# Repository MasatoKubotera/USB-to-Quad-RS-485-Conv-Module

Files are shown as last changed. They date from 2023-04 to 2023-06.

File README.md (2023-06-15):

<html lang="en">

<head>
    <meta charset="uft-8">
    <meta name="author" content="Masato Kubotera">
    <meta name="description" content="">
</head>

<body>
    <p><strong>This product is currently under development!</strong></p>
    <h1>USB to Quad RS-485 Conv. Module</h1>
        <p>
            This product is USB to 4 RS-485 conversion module. The FTDI FT4232H is used for USB to quad UART conversion, and the Analog Devices ADM3078E is used for UART to RS-485 conversion. USB is 2.0 High Speed (480 Mb/s) and RS-485 supports a maximum baud rate of 16 MBps. The RS-485 I/O voltage is 3.3 V and is supplied by USB bus power from the regulator on the board. This product has a internal EEPROM and programmable in-circuit over USB using a utility program called FT_PROG available from FTDI’s web site (www.ftdichip.com). <br><br>
            Note: For this product, RI must be RS485 enabled (Enables the RI pin to be used as the TXDEN signal for RS485 busses) using FT_PROG in order to convert USB to RS-485 for transmission.
        </p>
    <h2>Features Rev. 1</h2>
        <p>
            <table>
                <tr>
                    <th>Top Surface of PCB</th>
                    <th>Bottom Surface of PCB</th>
                    <th>Assembled Electronic Components</th>
                </tr>
                <tr>
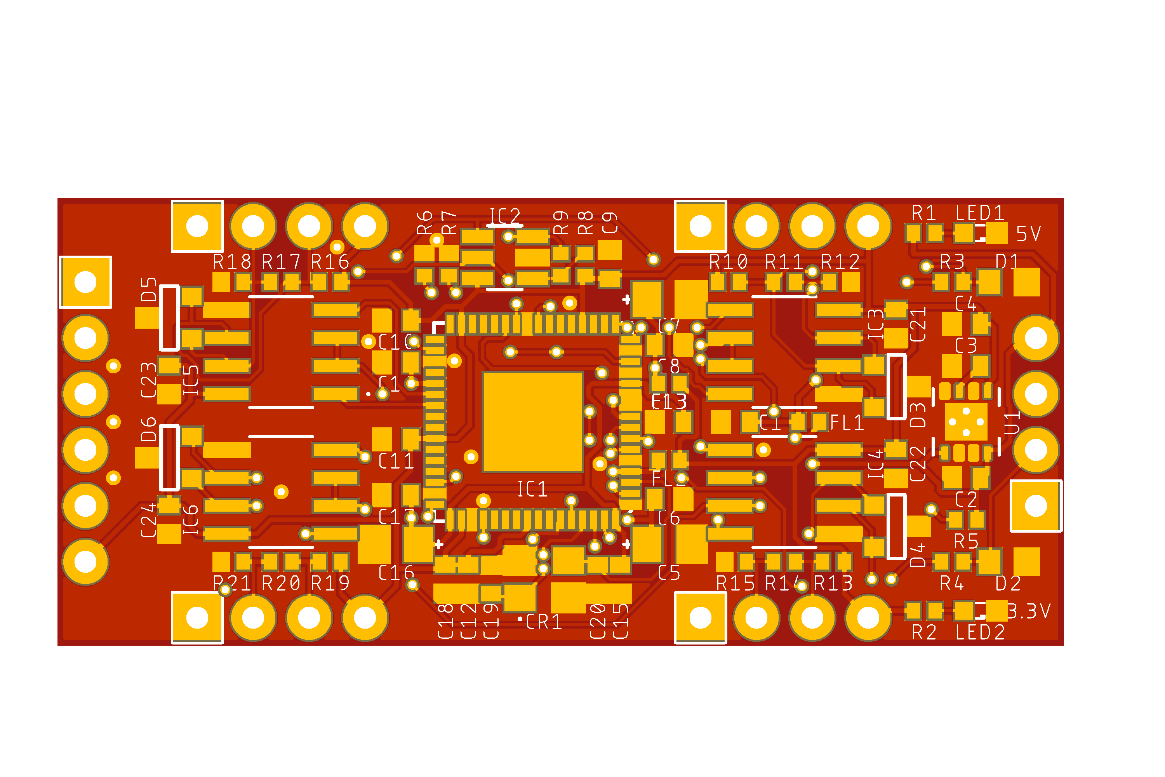
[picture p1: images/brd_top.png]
                    <td></td>
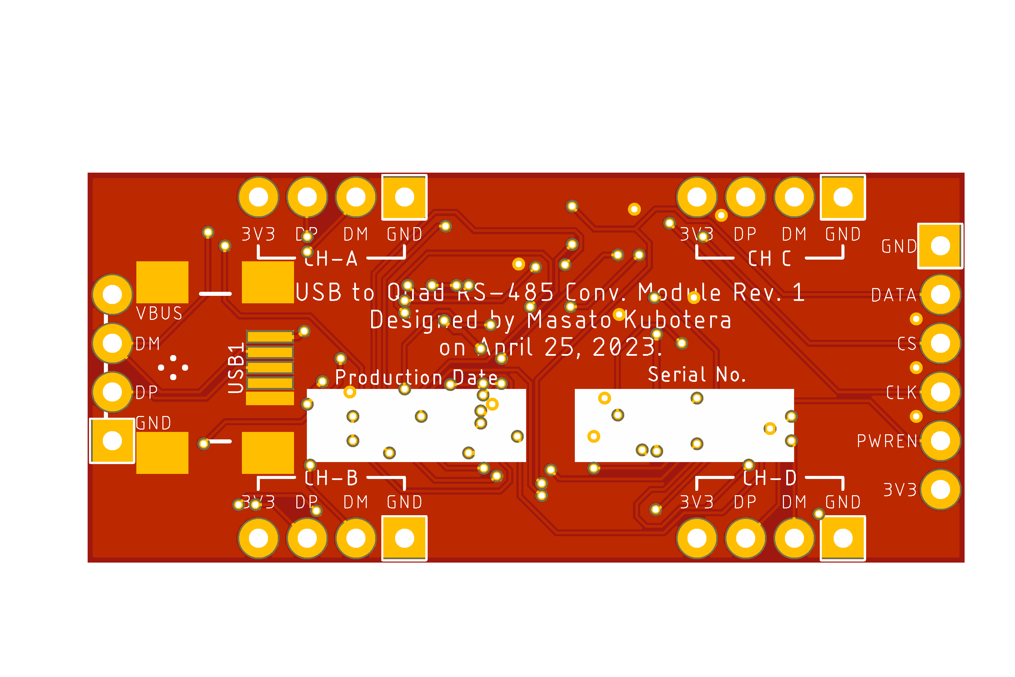
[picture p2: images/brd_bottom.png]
                    <td></td>
                    <td></td>
                </tr>
            </table>
        </p>
    <h3>PCB</h3>
        <p>
            <ul>
                <li>58 mm x 22.5 mm PCB layout</li>
                <li>
                    Two types of USB connectors
                    <ul>
                        <li>USB Mini-B Connector</li>
                        <li>1" (2.54mm) pitch through-holes for pin headers
                            <ul>
                                <li>VBUS</li>
                                <li>DM: USB Data Signal Minus</li>
                                <li>DP: USB Data Signal Plus</li>
                                <li>GND: Common Ground</li>
                            </ul>
                        </li>
                    </ul>
                </li>
                <li>
                    4 x RS-485 ports
                    <ul>
                        <li>1" (2.54mm) pitch through-holes for pin headers
                            <ul>
                                <li>3V3: 3.3 V power output (Power generated by the regulator on the board from USB bus power)</li>
                                <li>DP: RS-485 Data Signal Plus</li>
                                <li>DM: RS-485 Data Signal Minus</li>
                                <li>GND: Common Ground</li>
                            </ul>
                        </li>
                    </ul>
                </li>
                <li>
                    1 x Expansion port for FTDI FH4232HQ
                    <ul>
                        <li>1" (2.54mm) pitch through-holes for pin headers
                            <ul>
                                <li>3V3: 3.3 V power output (Power generated by the regulator on the board from USB bus power)</li>
                                <li>PWREN: Connected to FT4232HQ Pin#: 60 PWREN#</li>
                                <li>CLK: Connected to FT4232HQ Pin#: 62 EECLK</li>
                                <li>CS: Connected to FT4232HQ Pin#: 63 EECS</li>
                                <li>DATA: Connected to FT4232HQ Pin#: 61 EEDATA</li>
                                <li>GND: Common Ground</li>
                            </ul>
                    This port can be used for 4-channel transmit/receive LED display by decoding EEDATA data using 74HCT595, etc. Check the <a href="https://ftdichip.com/wp-content/uploads/2020/08/DS_FT4232H.pdf#page=33">Data Sheet</a> for details.
                        </li>
                    </ul>
                </li>
            </ul>
        </p>
    <h2>Development Environments</h2>
    <p>
        This product is designed with the following software.
            <ul>
                <li><a href="https://www.autodesk.com/products/eagle/overview">Autodesk Eagle 9.6.2</a></li>
            </ul>
    </p>
    <h2>Repository Contents</h2>
        <p>
            <dl>
                <dt><a href="/images">\images</a></dt>
                <dd>PCB preview images and capture of design screen</dd>
                <dt><a href="/libraries">\libraries</a></dt>
                <dd>Libraries used in Autodesk Eagle design</dd>
                <!--
                    <dt><a href="/documents">\documents</a> </dt>
                    <dd>Documentation for making and using this product</dd>
                -->
                <dt><a href="/pcb_order">\pcb_order</a> </dt>
                <dd>Gerber data and documentation for ordering PCB</dd>
                <dt><a href="/schematic.pdf">schematic.pdf</a></dt>
                <dd>Circuit diagram of this product</dd>
                <dt>*.brd</dt>
                <dd>Board wiring design file by Autodesk Eagle</dd>
                <dt>*.sch</dt>
                <dd>Circuit diagram design file by Autodesk Eagle</dd>
                <dt><a href="/.gitignore">.gitignore</a></dt>
                <dd>A file that tells Git not to track a particular file</dd>
                <dt><a href="/LICENSE">LICENSE</a></dt>
                <dd>License to use this product</dd>
            </dl>
        </p>
    <h2>Documentation</h2>
        <p>
            The following documents are available for this product.
            <ul>
                <li><a href="/pcb_order/README.md">\pcb_order\README.md</a>: Information for ordering the PCB</li>
            </ul>
        </p>
    <h2>References</h2>
        <p>
            This product was designed with reference to the following products.
            <ul>
                <li><a href="https://ftdichip.com/products/ft4232h-mini-module/">FTDI USB Hi-Speed FT4232H Evaluation Module: FT4232H Mini Module</a></li>
                <li><a href="https://kondo-robot.com/product/02133">KONDO RS485USB/Serial Conversion Adapter</a></li>
            </ul>
            In addition, the following documents were referenced in the design
            <ul>
                <li><a href="https://www.ftdichip.com/Support/Documents/AppNotes/AN_146_USB_Hardware_Design_Guidelines_for_FTDI_ICs.pdf">FTDI USB Hardware Design Guidelines for FTDI ICs</a></li>
                <li><a href="https://www.analog.com/media/en/analog-dialogue/volume-47/number-2/articles/safeguard-your-rs-485-communication-networks.pdf">Analog Devices Safeguard Your RS-485 Communication Networks from Harmful EMC Events</a></li>
                <li><a href="https://kondo-robot.com/w/wp-content/uploads/2014-B3M_series_manual_Ver.1.1.3.pdf#page=8">KONDO B3M Series Manual Ver1.13 pp.8</a></li>
            </ul>
        </p>
    <h2>Acknowledgements</h2>
        <p>
            The background to the development of this product was the development of QUADDXL, which was introduced in the following paper.
            <ul>
                <li>Bestmann, M., Güldenstein, J., Zhang, J. : High-Frequency Multi Bus Servo and Sensor Communication Using the Dynamixel Protocol. RoboCup 2019: Robot World Cup XXIII, pp.16–29 (2019)</li>
            </ul>
            Development data and other information on QUADDXL are available in the following repositories.
            <ul>
                <li><a href="https://github.com/bit-bots/bitbots_quaddxl">bit-bots/bitbots_quaddxl</a>: USB to RS485 Converter using FT4232H</li>
            </ul>
            I would like to take this opportunity to thank you.
        </p>
    <h2>Contact</h2>
        <p>
            If you have any questions, please contact the designer of this product, Masato Kubodera, by <a href="mailto:masato.kubotera@sustaina-op.com">e-mail</a>.<br>
            E-mail: <a href="mailto:masato.kubotera@sustaina-op.com">masato.kubotera@sustaina-op.com</a>
        </p>
    <h2>License Information</h2>
        <p>
            This product is open source. Please review the <a href="/LICENSE">LICENSE</a> for license information.<br>
            <br>
            This product by Masato Kubotera is licensed under a <a href="http://creativecommons.org/licenses/by-nc-sa/4.0/">Creative Commons Attribution-NonCommercial-ShareAlike 4.0 International License</a>.
        </p>
</body>
</html>

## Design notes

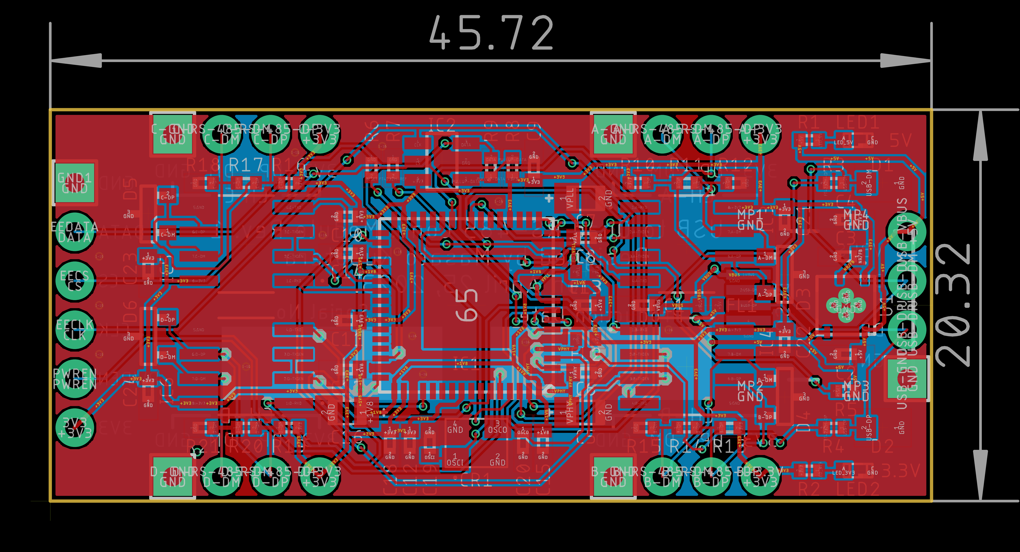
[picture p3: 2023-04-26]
images/brd.png

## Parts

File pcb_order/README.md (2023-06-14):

<html lang="en">

<head>
	<meta charset="uft-8">
	<meta name="author" content="Masato Kubotera">
    <meta name="description" content="">
</head>

<body>
	<h1>PCB / PCBA Order</h1>
        <p>
            PCB/PCBA ordering were outsourced to <a href="https://jlcpcb.com/">JLCPCB</a>.<br>
            The following files were used to generate files for PCB/PCBA orders.
            <ul>
                <li>Eagle Design File:
                    <a href="https://github.com/JLCPCB/jlcpcb-eagle/blob/master/design%20rules/jlcpcb-2layers.dru">jlcpcb-2layers.dru</a>
                </li>
                <li>Eagle CAM File:
                    <a href="https://github.com/JLCPCB/jlcpcb-eagle/blob/master/cam/jlcpcb_2_layer_v9.cam">jlcpcb_2_layer_v9.cam</a>
                </li>
                <li>BOM/CPL Exporter ULPs:
                    <a href="https://github.com/JLCPCB/jlcpcb-eagle/blob/master/ulps/jlcpcb_smta_exporter.ulp">jlcpcb_smta_exporter.ulp</a>
                </li>
            </ul>
            These are distributed in <a href="https://github.com/JLCPCB/jlcpcb-eagle">github.com/JLCPCB/jlcpcb-eagle</a>.<br>
        </p>
    <h2>PCB Order Specifications</h2>
        <p>           
            <table>
                <tr>
                    <th>PCB Top Image</th>
                    <th>PCB Bottom Image</th>
                </tr>
                <tr>
                    <td></td>
                    <td></td>
                </tr>
            </table>
            The following  files used to order the PCB and their specifications. 
            <ul>
                <li>Gerber data: <a href="Gerber_date.zip">Gerber_date.zip</a></li>
            </ul>
            <details close>
                <summary>Click for more specifications</summary>
                <ul>                
                    <li>Base Material: FR-4</li>
                    <li>Layers: 2</li>
                    <li>Dimension: 45.72 mm* 20.32 mm</li>
                    <li>Product Type: Industrial/Consumer electronics</li>
                    <li>Different Design: 1</li>
                    <li>Delivery Format: Single PCB</li>
                    <li>PCB Thickness: 1.6</li>
                    <li>Impedance Control: no</li>
                    <li>PCB Color: Red</li>
                    <li>Silkscreen: White</li>
                    <li>Surface Finish: HASL(with lead)</li>
                    <li>Outer Copper Weight: 1 oz</li>
                    <li>Via Covering: Tented</li>
                    <li>Board Outline Tolerance: ±0.2mm(Regular)</li>
                    <li>Confirm Production file: No</li>                
                    <li>Remove Order Number: Yes</li>
                    <li>Deburring/Edge rounding: No</li>
                    <li>Flying Probe Test: Fully Test</li>
                    <li>Gold Fingers: No</li>
                    <li>Castellated Holes: No</li>
                    <li>4-Wire Kelvin Test: No</li>
                    <li>Paper between PCBs: No</li>
                    <li>Appearance Quality: IPC Class 2 Standard</li>
                    <li>Silkscreen Technology: Ink-jet/Screen Printing</li>
                    <li>Package Box: With JLCPCB logo</li>
                </ul>
            </details>
        </p>
    <h2>PCBA Order Specifications</h2>
        <p>
            <table>
                <tr><th>PCBA Image</th></tr>
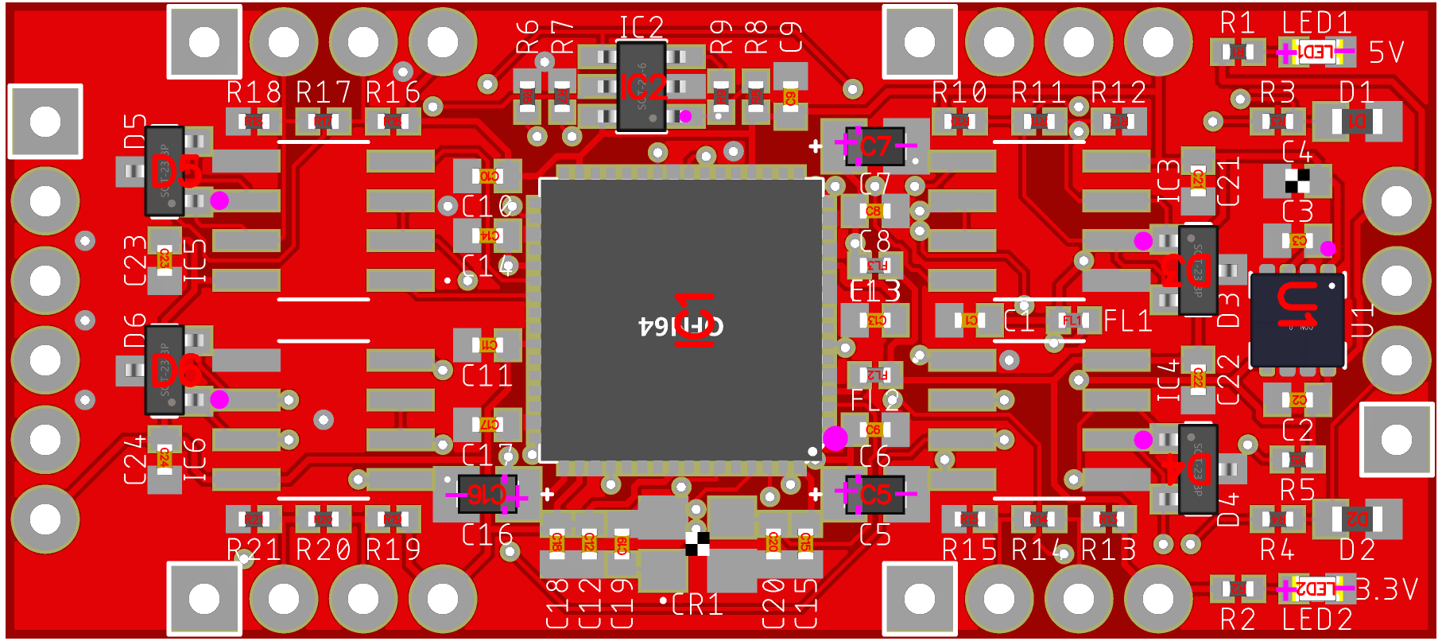
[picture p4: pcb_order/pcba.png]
                <tr><td></td></tr>
            </table>
            The following files used to order the PCBA and their specifications.
            <ul>
                <li>BOM File: <a href="USB-to-Quad-RS-485-Conv-Module_top_bom.csv">USB-to-Quad-RS-485-Conv-Module_top_bom.csv</a></li>
                <li>CPL File: <a href="USB-to-Quad-RS-485-Conv-Module_top_cpl.csv">USB-to-Quad-RS-485-Conv-Module_top_cpl.csv</a></li>
            </ul>
            The following components were installed by PCBA.
            <table>
                <tr>
                    <th>Part Image</th>
                    <th>Top Designator</th>
                    <th>MFR.Part #</th>
                    <th>JLCPCB Part #</th>
                    <th>Manufacturer</th>
                    <th>Part Detail</th>
                </tr>
                <tr>
                    <td></td>
                    <td>C1,C3</td>
                    <td>CC0402JRX7R9BB103</td>
                    <td><a href="https://jlcpcb.com/partdetail/Yageo-CC0402JRX7R9BB103/C272878">C272878</a></td>
                    <td>YAGEO</td>
                    <td>Multilayer Ceramic Capacitor SMD 10nF 50V ±5% X7R 0402</td>
                </tr>
                <tr>
                    <td></td>
                    <td>C2</td>
                    <td>CC0402KRX7R5BB105</td>
                    <td><a href="https://jlcpcb.com/partdetail/Yageo-CC0402KRX7R5BB105/C115046">C115046</a></td>
                    <td>YAGEO</td>
                    <td>Multilayer Ceramic Capacitor SMD 1uF 6.3V ±10% X7R 0402</td>
                </tr>
                <tr>
                    <td></td>
                    <td>C4</td>
                    <td>GRM155Z71A225KE01D</td>
                    <td><a href="https://jlcpcb.com/partdetail/3468099-GRM155Z71A225KE01D/C2997286">C2997286</a></td>
                    <td>Murata Electronics</td>
                    <td>Multilayer Ceramic Capacitor SMD 2.2uF 10V ±10% X7R 0402</td>
                </tr>
                <tr>
                    <td></td>
                    <td>C5,C7,C16</td>
                    <td>TAJR475K006RNJ</td>
                    <td><a href="https://jlcpcb.com/partdetail/KyoceraAvx-TAJR475K006RNJ/C308815">C308815</a></td>
                    <td>Kyocera AVX</td>
                    <td>Tantalum Capacitor SMD 4.7uF 6.3V ±10% 7Ω@100kHz 0805</td>
                </tr>
                <tr>
                    <td></td>
                    <td>C6,C8,C9,C10,C11,C12,C13,C14,C15,C17,C18,C21,C22,C23,C24</td>
                    <td>CC0402JRX7R7BB104</td>
                    <td><a href="https://jlcpcb.com/partdetail/Yageo-CC0402JRX7R7BB104/C541464">C541464</a></td>
                    <td>YAGEO</td>
                    <td>Multilayer Ceramic Capacitor SMD 100nF 16V ±5% X7R 0402</td>
                </tr>
                <tr>
                    <td></td>
                    <td>C19,C20</td>
                    <td>CC0402GRNPO9BN300</td>
                    <td><a href="https://jlcpcb.com/partdetail/Yageo-CC0402GRNPO9BN300/C277479">C277479</a></td>
                    <td>YAGEO</td>
                    <td>Multilayer Ceramic Capacitor SMD 30pF 50V ±2% NP0 0402</td>
                </tr>
                <tr>
                    <td></td>
                    <td>CR1</td>
                    <td>7V12006001</td>
                    <td><a href="https://jlcpcb.com/partdetail/TxcCorp-7V12006001/C5203634">C5203634</a></td>
                    <td>TXC Corp</td>
                    <td>Crystal 12Hz ±30ppm 12pF SMD 3225-4P</td>
                </tr>
                <tr>
                    <td></td>
                    <td>D1,D2</td>
                    <td>PGB1010603MR</td>
                    <td><a href="https://jlcpcb.com/partdetail/Littelfuse-PGB1010603MR/C142698">C142698</a></td>
                    <td><a href="https://m.littelfuse.com/products/polymer-esd-suppressors/pulseguard-esd-suppressors/pgb10603">Littelfuse</a></td>
                    <td>ESD Suppressor SMD 24V 0.06pF 0603</td>
                </tr>
                <tr>
                    <td></td>
                    <td>D3,D4,D5,D6</td>
                    <td>CDSOT23-SM712</td>
                    <td><a href="https://jlcpcb.com/partdetail/Bourns-CDSOT23SM712/C404012">C404012</a></td>
                    <td><a href="https://www.bourns.com/products/diodes/diode-arrays/product/CDSOT23-SM712">BOURNS</a></td>
                    <td>TVS Diodes Array SMD 7V 400W SOT-23</td>
                </tr>
                <tr>
                    <td></td>
                    <td>FL1,FL2,FL3</td>
                    <td>BLM15AX601SN1D</td>
                    <td><a href="https://jlcpcb.com/partdetail/MurataElectronics-BLM15AX601SN1D/C76886">C76886</a></td>
                    <td>Murata Electronics</td>
                    <td>Ferrite Bead SMD 600Ω ±25% 500mA 0402</td>
                </tr>
                <tr>
                    <td></td>
                    <td>IC1</td>
                    <td>FT4232HQ-REEL</td>
                    <td><a href="https://jlcpcb.com/partdetail/Ftdi-FT4232HQREEL/C2651882">C2651882</a></td>
                    <td><a href="https://ftdichip.com/products/ft4232hq/">FTDI</a></td>
                    <td>Quad High Speed USB to Multipurpose UART/MPSSE SMD 64-Pin QFN</td>
                </tr>
                <tr>
                    <td></td>
                    <td>IC2</td>
                    <td>93LC56BT-I/OT</td>
                    <td><a href="https://jlcpcb.com/partdetail/MicrochipTech-93LC56BT_IOT/C190271">C190271</a></td>
                    <td><a href="https://www.microchip.com/en-us/product/93LC56B">Microchip Tech</a></td>
                    <td>16-Bit EEPROM SMD SOT-23-6</td>
                </tr>
                <tr>
                    <td></td>
                    <td>LED1,LED2</td>
                    <td>SML-D12V1WT86</td>
                    <td><a href="https://jlcpcb.com/partdetail/RohmSemicon-SMLD12V1WT86/C253533">C253533</a></td>
                    <td>ROHM Semicon</td>
                    <td>Standard LED SMD RED 2.2V 20mA 630nm 0603</td>
                </tr>
                <tr>
                    <td></td>
                    <td>R1,R2</td>
                    <td>RC0402FR-071KL</td>
                    <td><a href="https://jlcpcb.com/partdetail/Yageo-RC0402FR071KL/C106235">C106235</a></td>
                    <td>YAGEO</td>
                    <td>Thick Film Resistor SMD 1kΩ 62.5mW ±1% 0402</td>
                </tr>
                <tr>
                    <td></td>
                    <td>R3,R4</td>
                    <td>RC0402FR-0710RL</td>
                    <td><a href="https://jlcpcb.com/partdetail/Yageo-RC0402FR0710RL/C138066">C138066</a></td>
                    <td>YAGEO</td>
                    <td>Thick Film Resistor SMD 10Ω 62.5mW ±1% 0402</td>
                </tr>
                <tr>
                    <td></td>
                    <td>R5</td>
                    <td>RC0402FR-0715KL</td>
                    <td><a href="https://jlcpcb.com/partdetail/12030-0402WGF1872TCE/C11476">C11476</a></td>
                    <td>YAGEO</td>
                    <td>Thick Film Resistor SMD 15kΩ 62.5mW ±1% 0402</td>
                </tr>
                <tr>
                    <td></td>
                    <td>R6,R8</td>
                    <td>RC0402FR-0710KL</td>
                    <td><a href="https://jlcpcb.com/partdetail/Yageo-RC0402FR0710KL/C60490">C60490</a></td>
                    <td>YAGEO</td>
                    <td>Thick Film Resistor SMD 10kΩ 62.5mW ±1% 0402</td>
                </tr>
                <tr>
                    <td></td>
                    <td>R7</td>
                    <td>RC0402FR-0712KL</td>
                    <td><a href="https://jlcpcb.com/partdetail/Yageo-RC0402FR0712KL/C114760">C114760</a></td>
                    <td>YAGEO</td>
                    <td>Thick Film Resistor SMD 12kΩ 62.5mW ±1% 0402</td>
                </tr>
                <tr>
                    <td></td>
                    <td>R9</td>
                    <td>RC0402FR-072KL</td>
                    <td><a href="https://jlcpcb.com/partdetail/Yageo-RC0402FR072KL/C60488">C60488</a></td>
                    <td>YAGEO</td>
                    <td>Thick Film Resistor SMD 2kΩ 62.5mW ±1% 0402</td>
                </tr>
                <tr>
                    <td></td>
                    <td>R10,R12,R13,R15,R16,R18,R19,R21</td>
                    <td>RC0402FR-07680RL</td>
                    <td><a href="https://jlcpcb.com/partdetail/Yageo-RC0402FR07680RL/C137948">C137948</a></td>
                    <td>YAGEO</td>
                    <td>Thick Film Resistor SMD 680Ω 62.5mW ±1% 0402</td>
                </tr>
                <tr>
                    <td></td>
                    <td>R11,R14,R17,R20</td>
                    <td>RC0402FR-07120RL</td>
                    <td><a href="https://jlcpcb.com/partdetail/Yageo-RC0402FR07120RL/C114758">C114758</a></td>
                    <td>YAGEO</td>
                    <td>Thick Film Resistor SMD 120Ω 62.5mW ±1% 0402</td>
                </tr>
                <tr>
                    <td></td>
                    <td>U1</td>
                    <td>TPS73533DRBT</td>
                    <td><a href="https://jlcpcb.com/partdetail/TexasInstruments-TPS73533DRBT/C115872">C115872</a></td>
                    <td><a href="https://www.ti.com/product/en-us/TPS735/part-details/TPS73533DRBT">Texas Instruments</a></td>
                    <td>Linear Voltage Regulator 3.3V 500mA SMD VSON-8-EP</td>
                </tr>
            </table>
            The following components could not be attached by PCBA due to stock availability.
            <table>
                <tr>
                    <th>Part Image</th>
                    <th>Top Designator</th>
                    <th>MFR.Part #</th>
                    <th>JLCPCB Part #</th>
                    <th>Manufacturer</th>
                    <th>Part Detail</th>
                </tr>
                <tr>
                    <td></td>
                    <td>IC3,IC4,IC5,IC6</td>
                    <td>ADM3078EARZ</td>
                    <td><a href="https://jlcpcb.com/partdetail/AnalogDevices-ADM3078EARZ/C658187">C658187</a></td>
                    <td><a href="https://www.analog.com/en/products/adm3078e.html">Analog Devices</a></td>
                    <td>RS-485/RS-422 Transceiver 16Mbps SMD SOIC-8</td>
                </tr>
            </table>
            These selected parts are listed in <a href="bom.xls">bom.xls</a>.<br>
            <details close>
                <summary>Click for more specifications</summary>
                <ul>                
                    <li>PCBA Type: Economic</li>
                    <li>Assembly Side: Top Side</li>
                    <li>Tooling holes: Added by JLCPCB</li>
                    <li>Confirm Parts Placement: No</li>
                </ul>
            </details>
        </p>
</body>

</html>

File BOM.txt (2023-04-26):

Partlist exported from C:/Users/Masato/OneDrive - Chiba Institute of Technology/CIT Brains/RoboCup2023/USB-to-Quad-RS-485-Conv-Module/USB-to-Quad-RS-485-Conv-Module.sch at 2023/04/25 19:38

Qty Value                          Device                         Package                                  Parts                                                                  Description                
2                                  LEDSML0603                     SML0603                                  LED1, LED2                                                             LED                        
2   0.01u                          C-USC0402                      C0402                                    C1, C3                                                                 CAPACITOR, American symbol 
15  0.1u                           C-USC0402                      C0402                                    C6, C8, C9, C10, C11, C12, C13, C14, C15, C17, C18, C21, C22, C23, C24 CAPACITOR, American symbol 
2   10                             R-US_R0402                     R0402                                    R3, R4                                                                 RESISTOR, American symbol  
2   10k                            R-US_R0402                     R0402                                    R6, R8                                                                 RESISTOR, American symbol  
4   120                            R-US_R0402                     R0402                                    R11, R14, R17, R20                                                     RESISTOR, American symbol  
1   12k                            R-US_R0402                     R0402                                    R7                                                                     RESISTOR, American symbol  
1   15k                            R-US_R0402                     R0402                                    R5                                                                     RESISTOR, American symbol  
2   1k                             R-US_R0402                     R0402                                    R1, R2                                                                 RESISTOR, American symbol  
1   1u                             C-USC0402                      C0402                                    C2                                                                     CAPACITOR, American symbol 
1   2.2u                           C-USC0402                      C0402                                    C4                                                                     CAPACITOR, American symbol 
1   2k                             R-US_R0402                     R0402                                    R9                                                                     RESISTOR, American symbol  
2   30p                            C-USC0402                      C0402                                    C19, C20                                                               CAPACITOR, American symbol 
3   4.7u                           TAJR475K006RNJ                 0805K                                    C5, C7, C16                                                                                       
8   680                            R-US_R0402                     R0402                                    R10, R12, R13, R15, R16, R18, R19, R21                                 RESISTOR, American symbol  
1   7V12006001                     7V12006001                     7V12006001                               CR1                                                                                               
1   93LC56BT-I/OT                  93LC56BT-I/OT                  SOT-23-6                                 IC2                                                                                               
4   ADM3078E                       ADM3078E                       SOIC-8                                   IC3, IC4, IC5, IC6                                                                                
3   BLM15AX601SN1D                 BLM15AX601SN1D                 BLM15AX601SN1D                           FL1, FL2, FL3                                                                                     
4   CDSOT23-SM712                  CDSOT23-SM712                  SOT-23-3                                 D3, D4, D5, D6                                                                                    
1   FT4232HQ                       FT4232HQ                       FT4232HQ                                 IC1                                                                                               
1   MINI_USB_B_SMD                 MINI_USB_B_SMD                 MINI_USB_B_SMD                           USB1                                                                                              
2   PGB1010603MR                   PGB1010603MR                   0603                                     D1, D2                                                                                            
1   TPS73533DRBT                   TPS73533DRBT                   SON-8                                    U1                                                                                                
1   USB-TO-QUAD-RS-485-CONV-MODULE USB-TO-QUAD-RS-485-CONV-MODULE USB-TO-QUAD-RS-485-CONV-MODULE-DIMENSION M1

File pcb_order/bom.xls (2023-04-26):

Comment | Designator | Footprint | JLCPCB Part #
FT4232HQ | IC1 | FT4232HQ | C2651882
93LC56BT-I/OT | IC2 | SOT-23-6 | C190271
10k | R6,R8 | R0402 | C60490
1u | C2 | C0402 | C115046
2.2u | C4 | C0402 | C2997286
1k | R1,R2 | R0402 | C106235
PGB1010603MR | D1,D2 | 603 | C142698
0.01u | C1,C3 | C0402 | C272878
120 | R11,R14,R17,R20 | R0402 | C114758
30p | C19,C20 | C0402 | C277479
CDSOT23-SM712 | D3,D4,D5,D6 | SOT-23-3 | C404012
TPS73533DRBT | U1 | SON-8 | C115872
4.7u | C5,C7,C16 | 0805K | C308815
12k | R7 | R0402 | C114760
10 | R3,R4 | R0402 | C138066
2k | R9 | R0402 | C60488
BLM15AX601SN1D | FL1,FL2,FL3 | BLM15AX601SN1D | C76886
680 | R10,R12,R13,R15,R16,R18,R19,R21 | R0402 | C137948
15k | R5 | R0402 | C114761
0.1u | C6,C8,C9,C10,C11,C12,C13,C14,C15,C17,C18,C21,C22,C23,C24 | C0402 | C541464
 | LED1,LED2 | C0402 | C253533
7V12006001 | CR1 | 7V12006001 | C5203634

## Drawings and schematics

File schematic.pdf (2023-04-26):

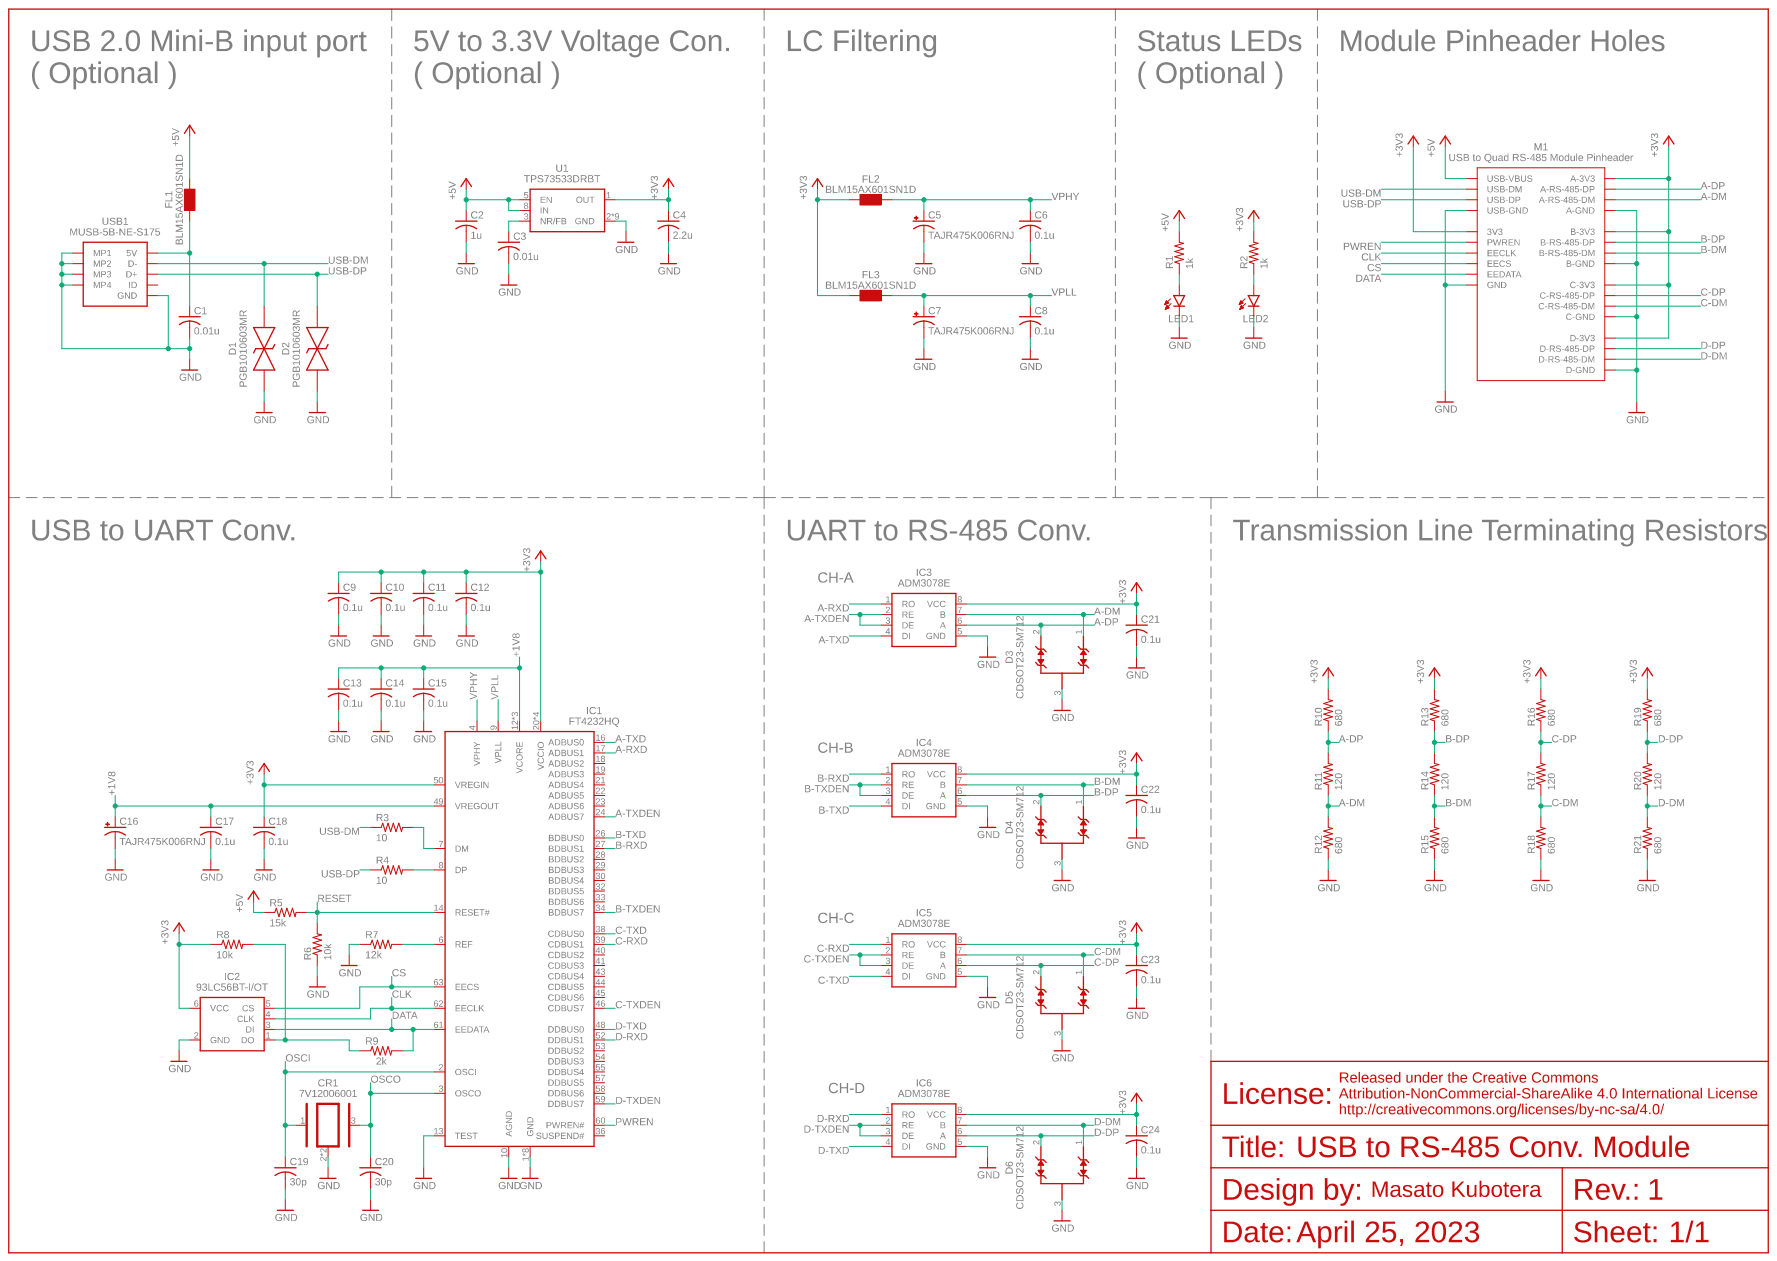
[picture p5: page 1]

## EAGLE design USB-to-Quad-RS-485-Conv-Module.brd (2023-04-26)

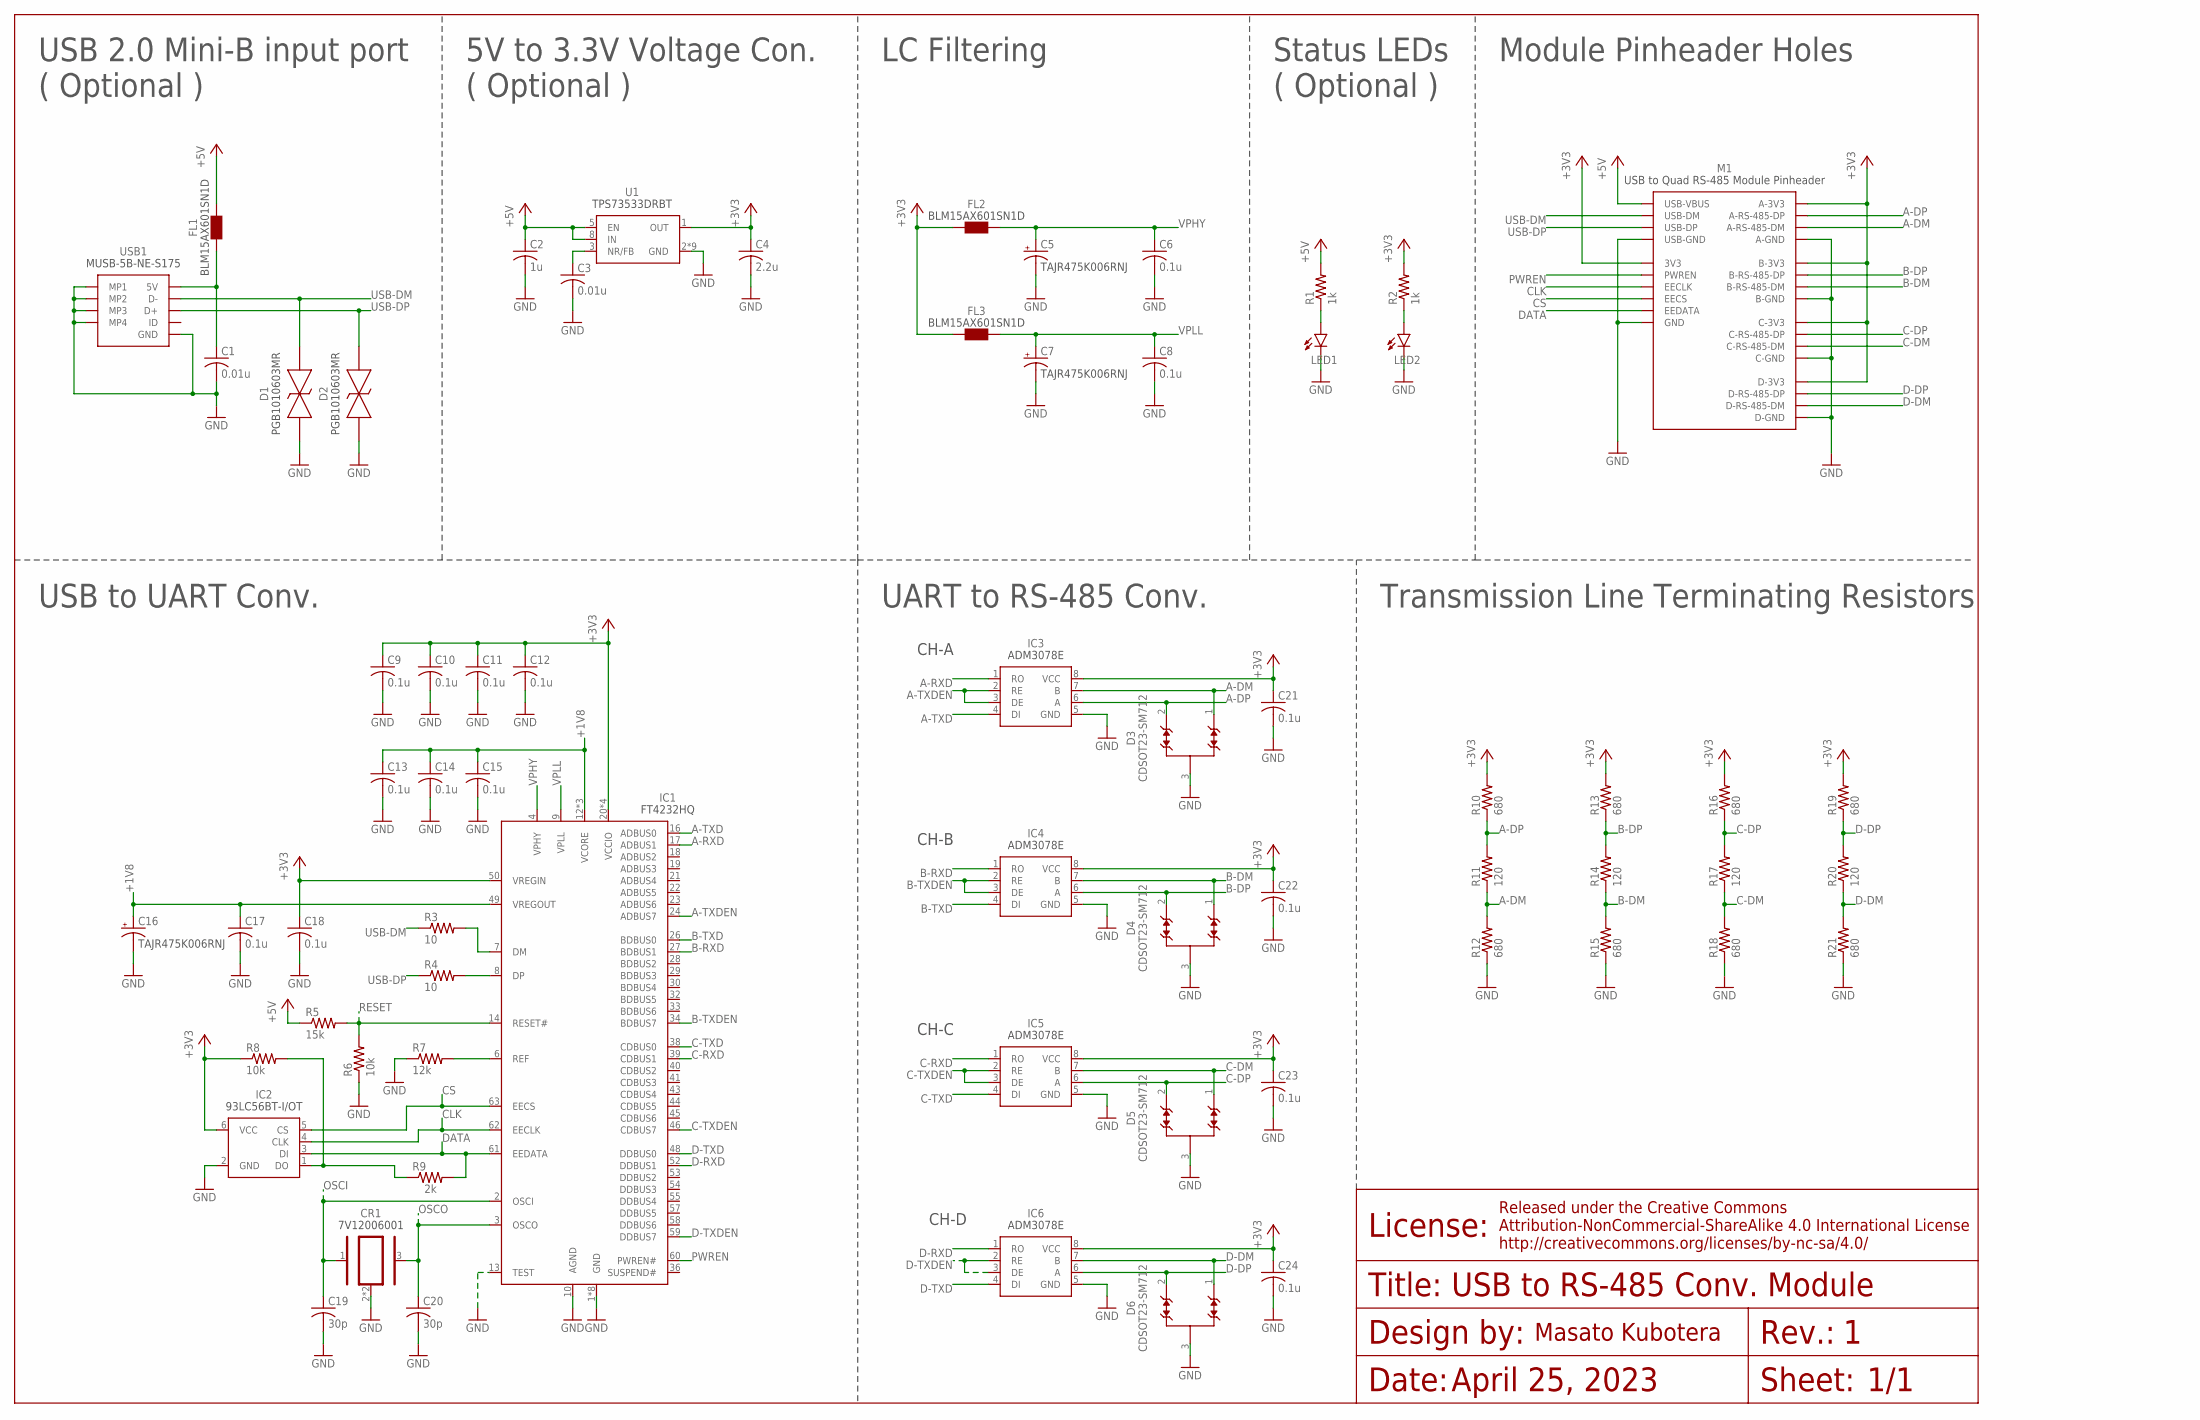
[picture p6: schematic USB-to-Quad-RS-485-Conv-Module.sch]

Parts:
C1, C3: 0.01u; C0402
C2: 1u; C0402
C4: 2.2u; C0402
C5, C7, C16: 4.7u; 0805K
C6, C8, C9, C10, C11, C12, C13, C14, C15, C17, C18, C21, C22, C23, C24: 0.1u; C0402
C19, C20: 30p; C0402
CR1: 7V12006001
D1, D2: PGB1010603MR; 0603
D3, D4, D5, D6: CDSOT23-SM712; SOT-23-3
FL1, FL2, FL3: BLM15AX601SN1D
IC1: FT4232HQ
IC2: 93LC56BT-I/OT; SOT-23-6
IC3, IC4, IC5, IC6: ADM3078E; SOIC-8
LED1, LED2: LEDSML0603; SML0603
M1: USB-TO-QUAD-RS-485-CONV-MODULE; USB-TO-QUAD-RS-485-CONV-MODULE-DIMENSION
R1, R2: 1k; R0402
R3, R4: 10; R0402
R5: 15k; R0402
R6, R8: 10k; R0402
R7: 12k; R0402
R9: 2k; R0402
R10, R12, R13, R15, R16, R18, R19, R21: 680; R0402
R11, R14, R17, R20: 120; R0402
U1: TPS73533DRBT; SON-8
USB1: MINI_USB_B_SMD

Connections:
+1V8: C13.1, C14.1, C15.1, C16.1 (+), C17.1, IC1.12 (VCORE), IC1.37 (VCORE), IC1.49 (VREGOUT), IC1.64 (VCORE)
+3V3: C4.1, C9.1, C10.1, C11.1, C12.1, C18.1, C21.1, C22.1, C23.1, C24.1, FL2.1, FL3.1, IC1.20 (VCCIO), IC1.31 (VCCIO), IC1.42 (VCCIO), IC1.50 (VREGIN), IC1.56 (VCCIO), IC2.6 (VCC), IC3.8 (VCC), IC4.8 (VCC), IC5.8 (VCC), IC6.8 (VCC), M1.3V3, M1.A-3V3, M1.B-3.3V (B-3V3), M1.C-3V3, M1.D-3V3, R2.2, R8.1, R10.2, R13.2, R16.2, R19.2, U1.1 (OUT)
+5V: C2.1, FL1.2, M1.USB-VBUS, R1.2, R5.1, U1.5 (EN), U1.8 (IN)
A-DM: D3.1, IC3.7 (B), M1.A-RS-485-DM, R11.1, R12.2
A-DP: D3.2, IC3.6 (A), M1.A-RS-485-DP, R10.1, R11.2
A-RXD: IC1.17 (ADBUS1), IC3.1 (RO)
A-TXD: IC1.16 (ADBUS0), IC3.4 (DI)
A-TXDEN: IC1.24 (ADBUS7), IC3.2 (RE), IC3.3 (DE)
B-DM: D4.1, IC4.7 (B), M1.B-RS-485-DM, R14.1, R15.2
B-DP: D4.2, IC4.6 (A), M1.B-RS-485-DP, R13.1, R14.2
B-RXD: IC1.27 (BDBUS1), IC4.1 (RO)
B-TXD: IC1.26 (BDBUS0), IC4.4 (DI)
B-TXDEN: IC1.34 (BDBUS7), IC4.2 (RE), IC4.3 (DE)
C-DM: D5.1, IC5.7 (B), M1.C-RS-485-DM, R17.1, R18.2
C-DP: D5.2, IC5.6 (A), M1.C-RS-485-DP, R16.1, R17.2
C-RXD: IC1.39 (CDBUS1), IC5.1 (RO)
C-TXD: IC1.38 (CDBUS0), IC5.4 (DI)
C-TXDEN: IC1.46 (CDBUS7), IC5.2 (RE), IC5.3 (DE)
CLK: IC1.62 (EECLK), IC2.4 (CLK), M1.EECLK
CS: IC1.63 (EECS), IC2.5 (CS), M1.EECS
D-DM: D6.1, IC6.7 (B), M1.D-RS-485-DM, R20.1, R21.2
D-DP: D6.2, IC6.6 (A), M1.D-RS-485-DP, R19.1, R20.2
D-RXD: IC1.52 (DDBUS1), IC6.1 (RO)
D-TXD: IC1.48 (DDBUS0), IC6.4 (DI)
D-TXDEN: IC1.59 (DDBUS7), IC6.2 (RE), IC6.3 (DE)
DATA: IC1.61 (EEDATA), IC2.3 (DI), M1.EEDATA, R9.2
FT4232H-DM: IC1.7 (DM), R3.2
FT4232H-DP: IC1.8 (DP), R4.2
FT4232H-REF: IC1.6 (REF), R7.2
GND: C1.2, C2.2, C3.2, C4.2, C5.2 (-), C6.2, C7.2 (-), C8.2, C9.2, C10.2, C11.2, C12.2, C13.2, C14.2, C15.2, C16.2 (-), C17.2, C18.2, C19.2, C20.2, C21.2, C22.2, C23.2, C24.2, CR1.2, CR1.4, D1.1, D2.1, D3.3, D4.3, D5.3, D6.3, IC1.1 (GND), IC1.5 (GND), IC1.10 (AGND), IC1.11 (GND), IC1.13 (TEST), IC1.15 (GND), IC1.25 (GND), IC1.35 (GND), IC1.47 (GND), IC1.51 (GND), IC2.2 (GND), IC3.5 (GND), IC4.5 (GND), IC5.5 (GND), IC6.5 (GND), LED1.C, LED2.C, M1.A-GND, M1.B-GND, M1.C-GND, M1.D-GND, M1.GND1 (GND), M1.USB-GND, R6.1, R7.1, R12.1, R15.1, R18.1, R21.1, U1.2 (GND), U1.4 (GND), U1.6 (GND), U1.7 (GND), U1.9 (GND), U1.10 (GND), U1.11 (GND), U1.12 (GND), U1.13 (GND), USB1.5 (GND), USB1.MP1, USB1.MP2, USB1.MP3, USB1.MP4
LED_3V3: LED2.A, R2.1
LED_5V: LED1.A, R1.1
NR/FB: C3.1, U1.3 (NR/FB)
OSCI: C19.1, CR1.1, IC1.2 (OSCI)
OSCO: C20.1, CR1.3, IC1.3 (OSCO)
PULLUP-DATA: IC2.1 (DO), R8.2, R9.1
PWREN: IC1.60 (PWREN#), M1.PWREN
RESET: IC1.14 (RESET#), R5.2, R6.2
USB-DM: D1.2, M1.USB-DM, R3.1, USB1.2 (D-)
USB-DP: D2.2, M1.USB-DP, R4.1, USB1.3 (D+)
VBUS: C1.1, FL1.1, USB1.1 (5V)
VPHY: C5.1 (+), C6.1, FL2.2, IC1.4 (VPHY)
VPLL: C7.1 (+), C8.1, FL3.2, IC1.9 (VPLL)

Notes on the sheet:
USB to UART Conv.
UART to RS-485 Conv.
CH-A
CH-D
CH-C
CH-B
Transmission Line Terminating Resistors
Module Pinheader Holes
Status LEDs ( Optional )
LC Filtering
5V to 3.3V Voltage Con. ( Optional )
USB 2.0 Mini-B input port ( Optional )
1/1
April 25, 2023
USB to RS-485 Conv. Module

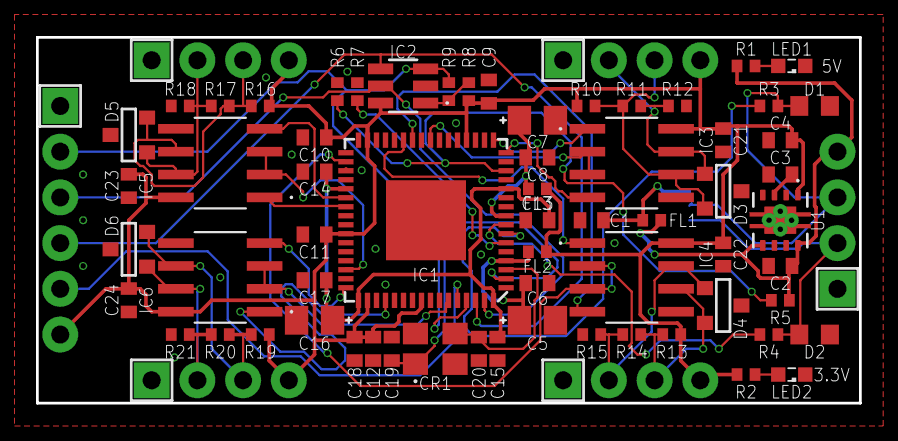
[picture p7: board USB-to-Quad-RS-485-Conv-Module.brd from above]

Board: 2 copper layers, 45.7 x 20.3 mm, 66 parts (1 on the bottom side), 43 nets.

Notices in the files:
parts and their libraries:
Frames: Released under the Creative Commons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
